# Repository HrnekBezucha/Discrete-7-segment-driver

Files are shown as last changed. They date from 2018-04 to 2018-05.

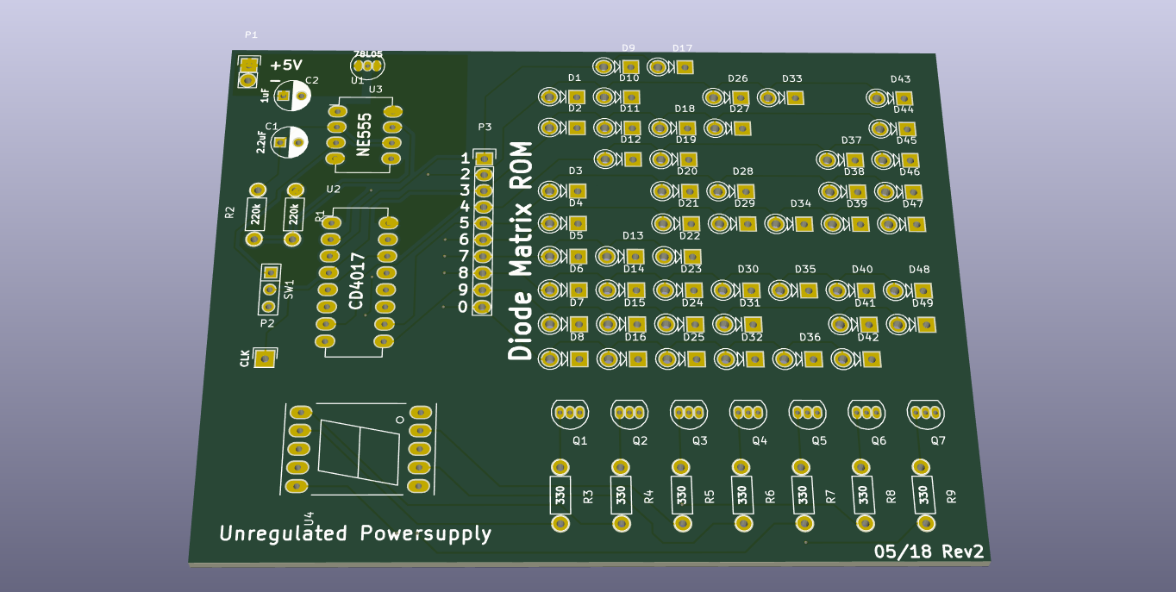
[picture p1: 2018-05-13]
discrete7segment.png

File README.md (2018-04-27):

# Discrete-7-segment-driver
7-segment display driver with a discrete diode ROM

The matrix of diodes is hardwired memory.
Each row is one word/byte with the 
length of 7 bits. The circuit 'stores' data
for displaying a number on a 7 segment LED display
(hence 7 bit word)
I made the memory and the display from
discrete diodes and the only chips are for
changing the address. Counting up at 1Hz frequency.
It would also work by putting logic HIGH on anode
of one of the leftmost diodes and get your output
on the bottom. That's where the display is wired.

It's an educational board with a bit of computer
history. This is what the pioneers of computing
used for microcode. Storing vital data, such as
the instruction set and boot sequence.

You can read some more about it on my blog
https://unregulatedpowersupply.wordpress.com/

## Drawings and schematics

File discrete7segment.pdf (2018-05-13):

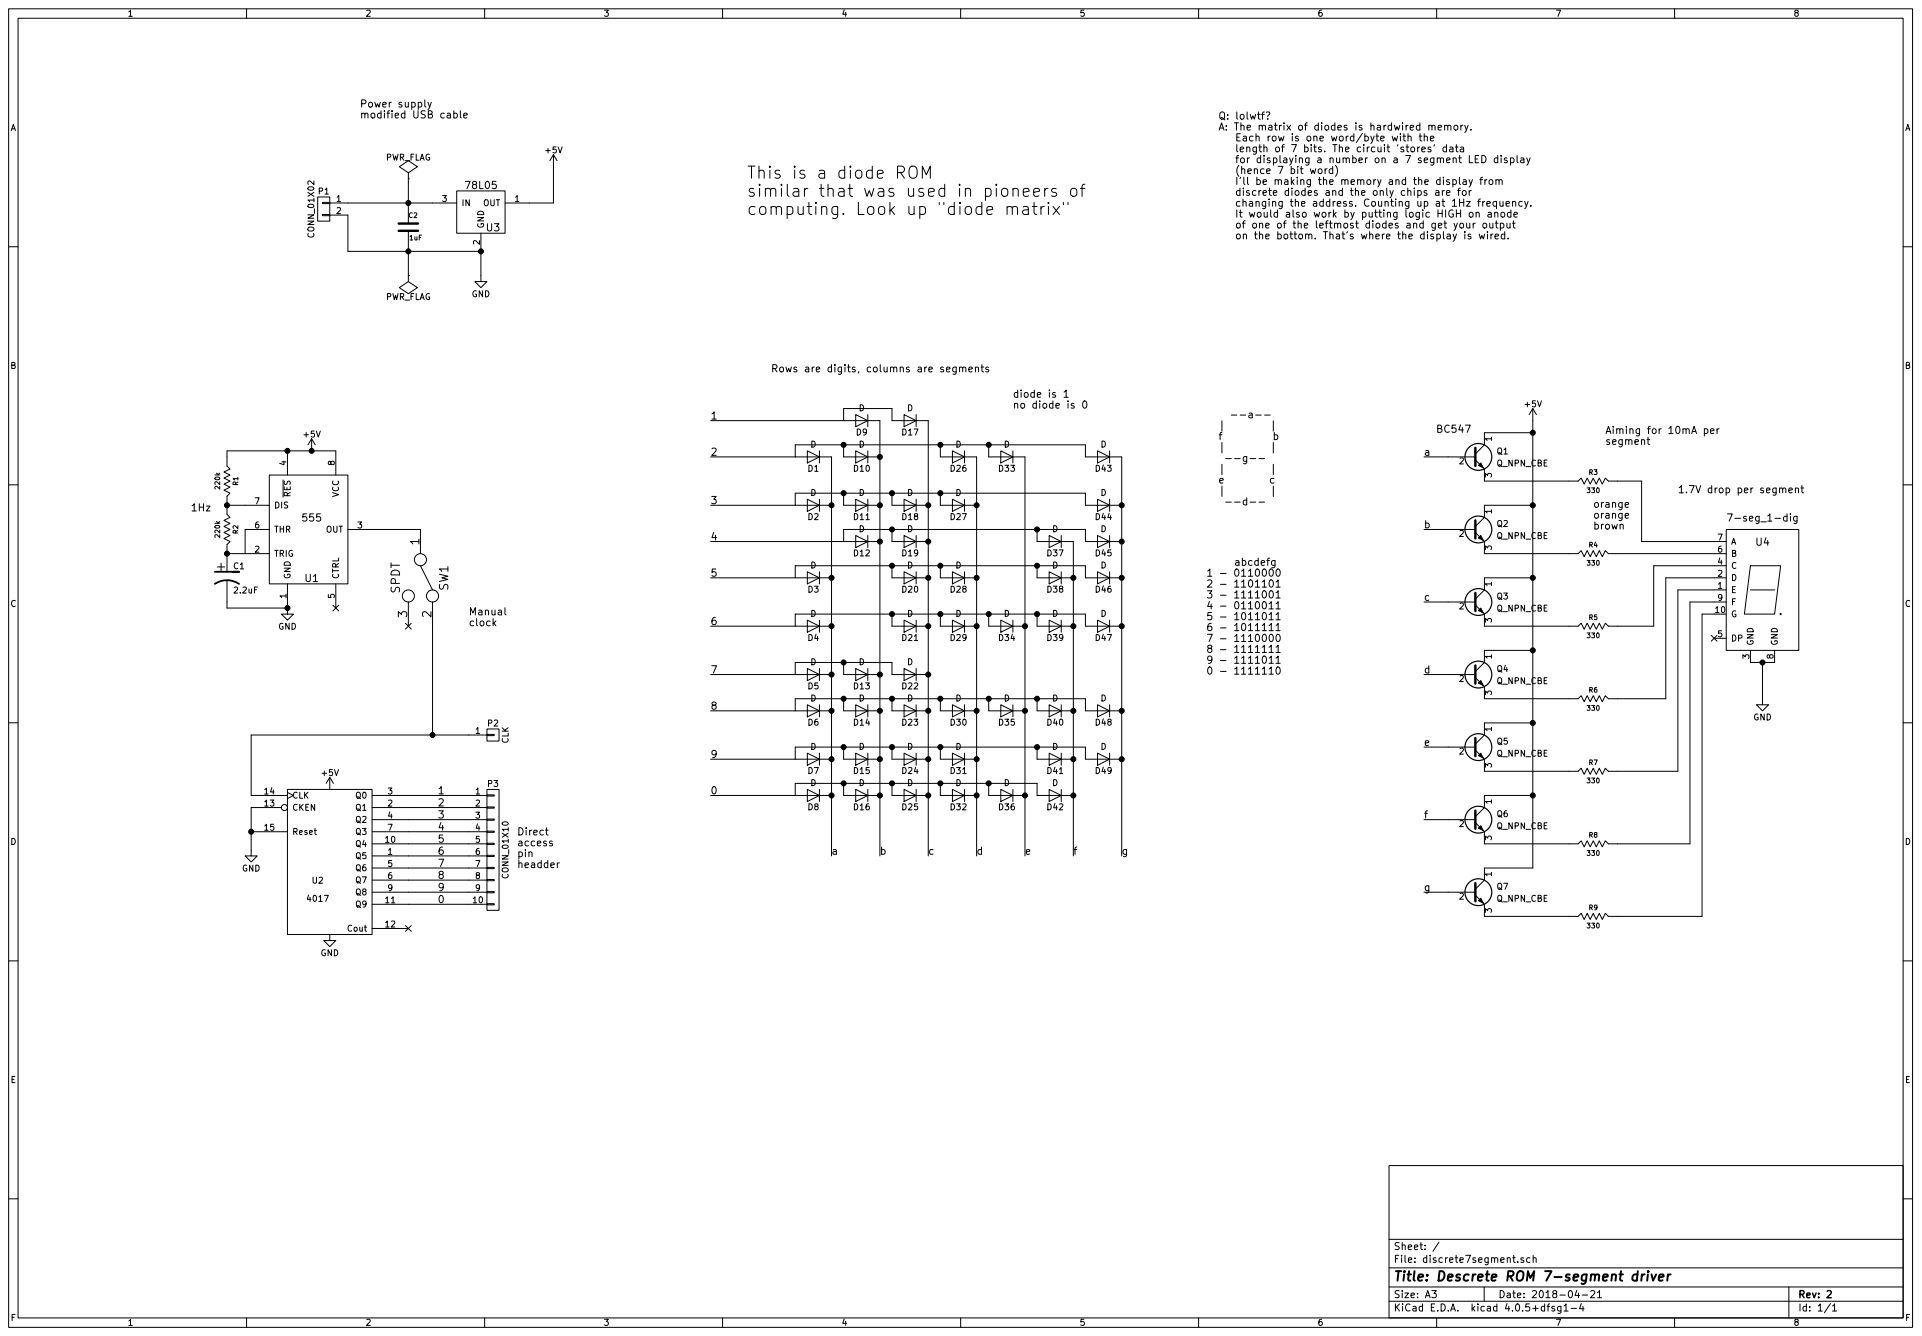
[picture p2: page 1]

Power supply
modified USB cable
D8D This is a diode ROM
similar that was used in pioneers of
computing. Look up "diode matrix"

Q: lolwtf?
A: The matrix of diodes is hardwired memory.
Each row is one word/byte with the
length of 7 bits. The circuit 'stores' data
for displaying a number on a 7 segment LED display
(hence 7 bit word)
I'll be making the memory and the display from
discrete diodes and the only chips are for
changing the address. Counting up at 1Hz frequency.
It would also work by putting logic HIGH on anode
of one of the leftmost diodes and get your output

on the bottom. That's where the display is wired. diode is 1

Rows are digits, columns are segments

brown Aiming for 10mA per
7-seg_1-dig GND

2 SPDT SW1 Manual clock Direct access pin

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
Id: 1/1 Title: Descrete ROM 7-segment driver

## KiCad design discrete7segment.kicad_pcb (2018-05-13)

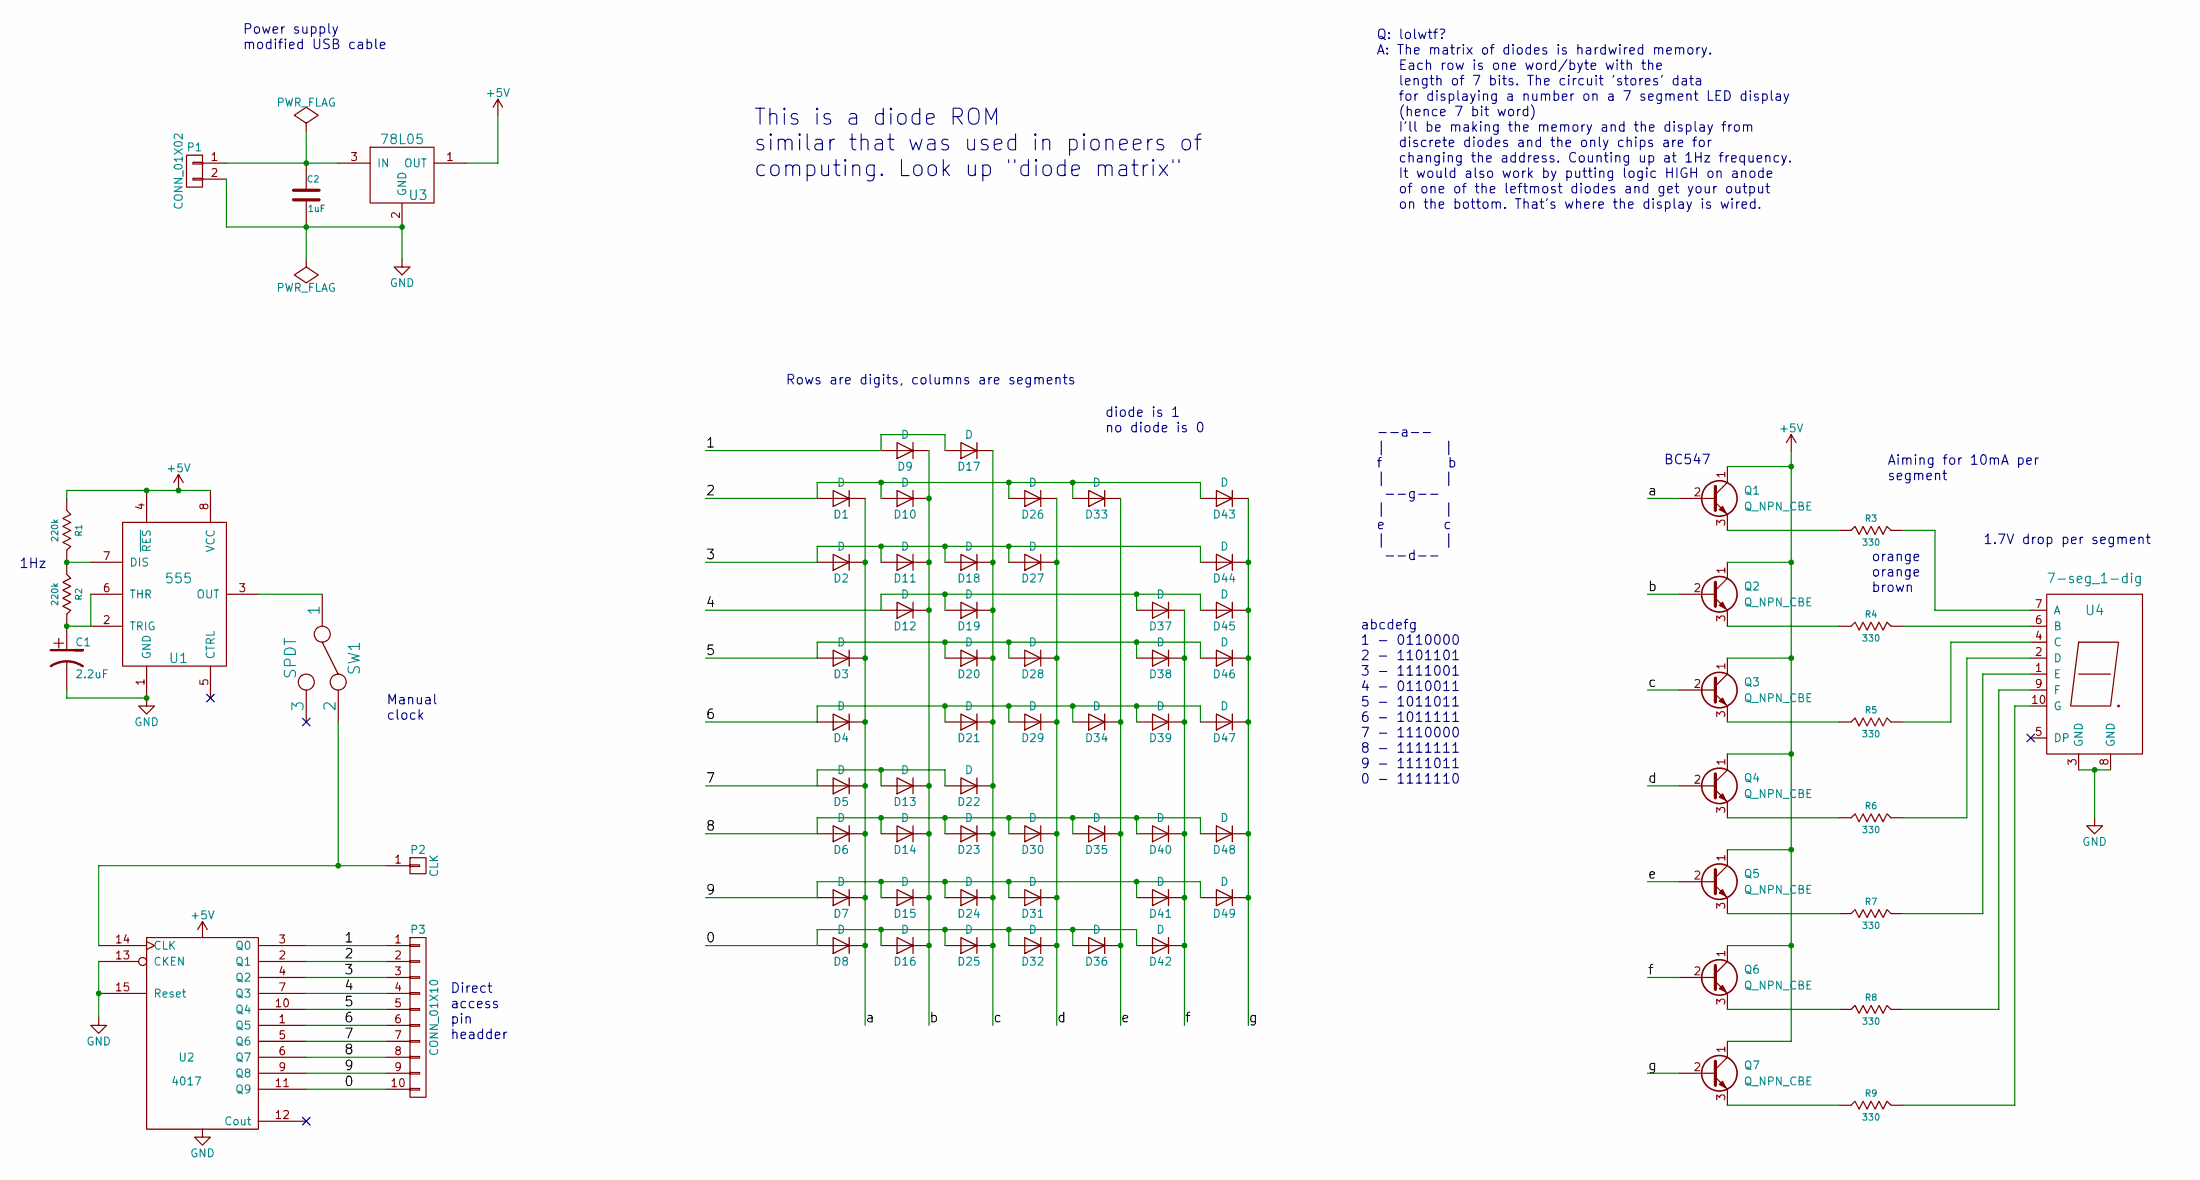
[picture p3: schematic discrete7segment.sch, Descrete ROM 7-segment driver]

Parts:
C1: 2.2uF; C_Radial_D5_L6_P2.5
C2: 1uF; C_Radial_D5_L6_P2.5
D1, D2, D3, D4, D5, D6, D7, D8, D9, D10, D11, D12, D13, D14, D15, D16, D17, D18, D19, D20, D21, D22, D23, D24, D25, D26, D27, D28, D29, D30, D31, D32, D33, D34, D35, D36, D37, D38, D39, D40, D41, D42, D43, D44, D45, D46, D47, D48, D49: D; Diode_DO-41_SOD81_Vertical_KathodeUp
P1: CONN_01X02; Pin_Header_Straight_1x02
P2: CLK; Pin_Header_Straight_1x01
P3: CONN_01X10; Pin_Header_Straight_1x10
Q1, Q2, Q3, Q4, Q5, Q6, Q7: Q_NPN_CBE; TO-92_Inline_Narrow_Oval
R1, R2: 220k; Resistor_Horizontal_RM7mm
R3, R4, R5, R6, R7, R8, R9: 330; Resistor_Horizontal_RM7mm
SW1: SPDT; SW_Micro_SPST
U1: 555; DIP-8_W7.62mm_LongPads
U2: 4017; DIP-16_W7.62mm_LongPads
U3: 78L05; TO-92_Inline_Narrow_Oval
U4: 7-seg_1-dig; 7SegmentLED_LTS6760_LTS6780

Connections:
+5V: Q1.1 (C), Q2.1 (C), Q3.1 (C), Q4.1 (C), Q5.1 (C), Q6.1 (C), Q7.1 (C), R1.1 (A), U1.4 (~RES), U1.8 (VCC), U2.16 (VDD), U3.1 (OUT)
/0: D8.2 (A), D16.2 (A), D25.2 (A), D32.2 (A), D36.2 (A), D42.2 (A), P3.10, U2.11 (Q9)
/1: D9.2 (A), D17.2 (A), P3.1, U2.3 (Q0)
/2: D1.2 (A), D10.2 (A), D26.2 (A), D33.2 (A), D43.2 (A), P3.2, U2.2 (Q1)
/3: D2.2 (A), D11.2 (A), D18.2 (A), D27.2 (A), D44.2 (A), P3.3, U2.4 (Q2)
/4: D12.2 (A), D19.2 (A), D37.2 (A), D45.2 (A), P3.4, U2.7 (Q3)
/5: D3.2 (A), D20.2 (A), D28.2 (A), D38.2 (A), D46.2 (A), P3.5, U2.10 (Q4)
/6: D4.2 (A), D21.2 (A), D29.2 (A), D34.2 (A), D39.2 (A), D47.2 (A), P3.6, U2.1 (Q5)
/7: D5.2 (A), D13.2 (A), D22.2 (A), P3.7, U2.5 (Q6)
/8: D6.2 (A), D14.2 (A), D23.2 (A), D30.2 (A), D35.2 (A), D40.2 (A), D48.2 (A), P3.8, U2.6 (Q7)
/9: D7.2 (A), D15.2 (A), D24.2 (A), D31.2 (A), D41.2 (A), D49.2 (A), P3.9, U2.9 (Q8)
/a: D1.1 (K), D2.1 (K), D3.1 (K), D4.1 (K), D5.1 (K), D6.1 (K), D7.1 (K), D8.1 (K), Q1.2 (B)
/b: D9.1 (K), D10.1 (K), D11.1 (K), D12.1 (K), D13.1 (K), D14.1 (K), D15.1 (K), D16.1 (K), Q2.2 (B)
/c: D17.1 (K), D18.1 (K), D19.1 (K), D20.1 (K), D21.1 (K), D22.1 (K), D23.1 (K), D24.1 (K), D25.1 (K), Q3.2 (B)
/d: D26.1 (K), D27.1 (K), D28.1 (K), D29.1 (K), D30.1 (K), D31.1 (K), D32.1 (K), Q4.2 (B)
/e: D33.1 (K), D34.1 (K), D35.1 (K), D36.1 (K), Q5.2 (B)
/f: D37.1 (K), D38.1 (K), D39.1 (K), D40.1 (K), D41.1 (K), D42.1 (K), Q6.2 (B)
/g: D43.1 (K), D44.1 (K), D45.1 (K), D46.1 (K), D47.1 (K), D48.1 (K), D49.1 (K), Q7.2 (B)
GND: C1.2, C2.2, P1.2, U1.1 (GND), U2.8 (VSS), U2.13 (CKEN), U2.15 (Reset), U3.2 (GND), U4.3 (GND), U4.8 (GND)
unnamed: C1.1, R2.2 (K), U1.2 (TRIG), U1.6 (THR)
unnamed: C2.1, P1.1, U3.3 (IN)
unnamed: P2.1, SW1.2, U2.14 (CLK)
unnamed: Q1.3 (E), R3.1 (A)
unnamed: Q2.3 (E), R4.1 (A)
unnamed: Q3.3 (E), R5.1 (A)
unnamed: Q4.3 (E), R6.1 (A)
unnamed: Q5.3 (E), R7.1 (A)
unnamed: Q6.3 (E), R8.1 (A)
unnamed: Q7.3 (E), R9.1 (A)
unnamed: R1.2 (K), R2.1 (A), U1.7 (DIS)
unnamed: R3.2 (K), U4.7 (A)
unnamed: R4.2 (K), U4.6 (B)
unnamed: R5.2 (K), U4.4 (C)
unnamed: R6.2 (K), U4.2 (D)
unnamed: R7.2 (K), U4.1 (E)
unnamed: R8.2 (K), U4.9 (F)
unnamed: R9.2 (K), U4.10 (G)
unnamed: SW1.1, U1.3 (OUT)

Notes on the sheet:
This is a diode ROM similar that was used in pioneers of computing. Look up "diode matrix"
Rows are digits, columns are segments
--a-- | | f b | | --g-- | | e c | | --d--
Power supply modified USB cable
1Hz
abcdefg 1 - 0110000 2 - 1101101 3 - 1111001 4 - 0110011 5 - 1011011 6 - 1011111 7 - 1110000 8 - 1111111 9 - 1111011 0 - 1111110
Q: lolwtf? A: The matrix of diodes is hardwired memory. Each row is one word/byte with the length of 7 bits. The circuit 'stores' data for displaying a number on a 7 segment LED display (hence 7 bit word) I'll be making the memory and the display from discrete diodes and the only chips are for chan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
diode is 1 no diode is 0
1.7V drop per segment
orange orange brown
Aiming for 10mA per segment
Manual clock
Direct access pin headder
BC547

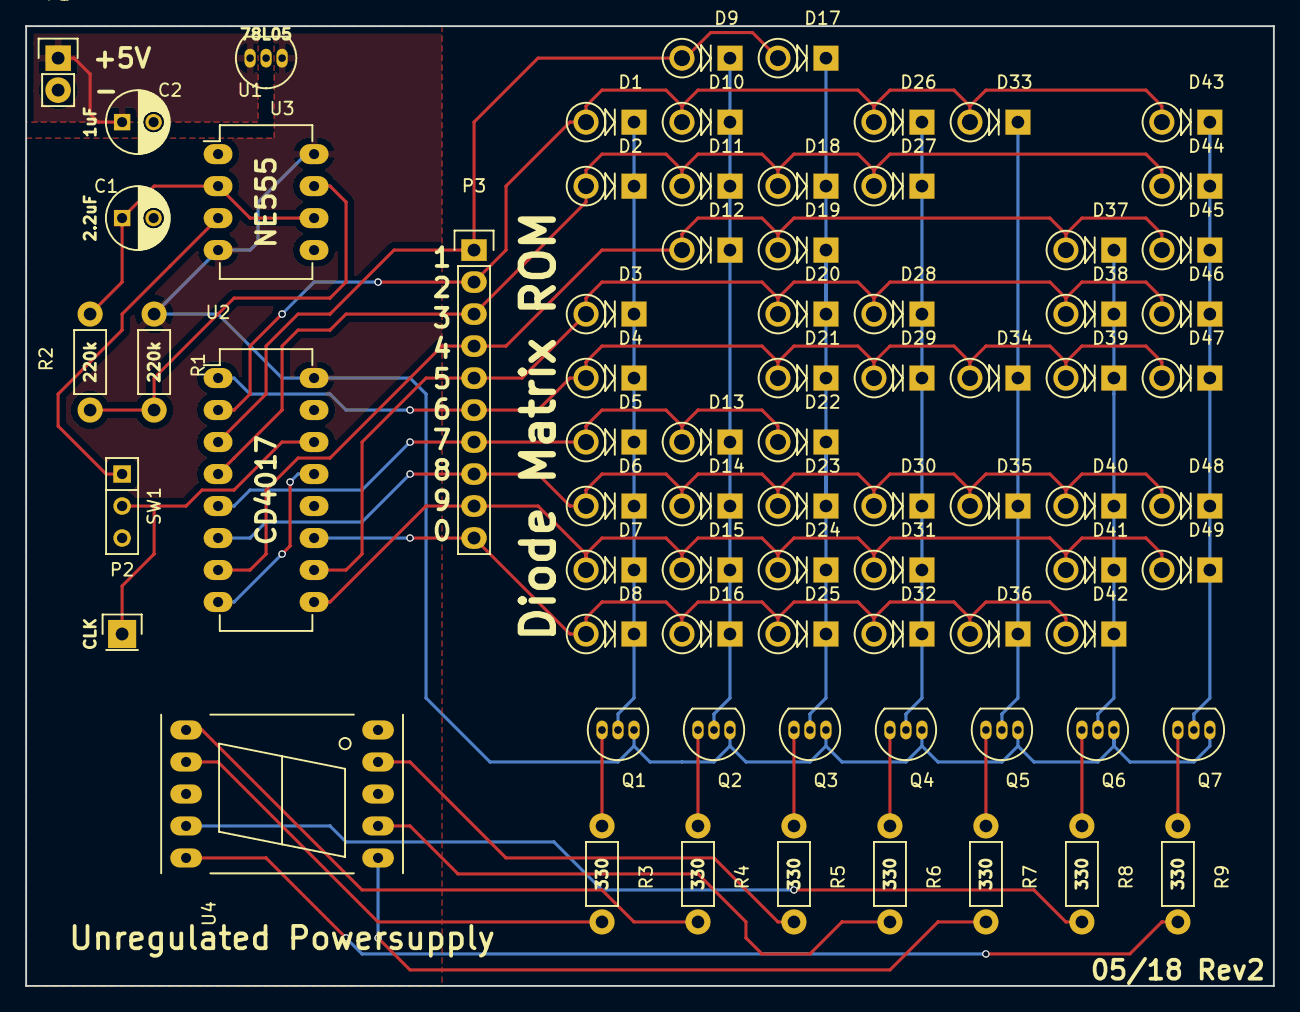
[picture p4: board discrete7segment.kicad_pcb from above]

Board: 2 copper layers, 99.1 x 76.2 mm, 75 parts (0 on the bottom side), 38 nets.

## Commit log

2018-04-22 layout begun
    [discrete7segment.kicad_pcb, discrete7segment.sch]
2018-04-22 generated schematic pdf
    [discrete7segment.sch]
2018-04-22 done digit
    [discrete7segment.kicad_pcb]
2018-04-22 board finished
    [discrete7segment.kicad_pcb]
2018-04-23 found bugs, needs rework
    [discrete7segment.kicad_pcb, discrete7segment.sch]
2018-04-25 layout from scratch
    [discrete7segment.kicad_pcb]
2018-04-25 layout finished
    [discrete7segment.kicad_pcb, discrete7segment.sch]
2018-05-12 vast redesign
    [discrete7segment.sch]
2018-05-12 through hole design
    [discrete7segment.sch]
2018-05-12 new layout initiated
    [discrete7segment.kicad_pcb]
2018-05-12 layout done
    [discrete7segment.kicad_pcb, discrete7segment.sch]
2018-05-12 through hole layout
    [discrete7segment.kicad_pcb]
2018-05-13 erc passed
    [discrete7segment.kicad_pcb, discrete7segment.sch]
2018-05-13 THT generation
    [discrete7segment-B.Cu.gbr, discrete7segment-B.Mask.gbr, discrete7segment-B.SilkS.gbr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]
